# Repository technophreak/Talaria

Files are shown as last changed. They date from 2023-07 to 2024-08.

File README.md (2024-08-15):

# Mods for Talaria Sting R MX4 #

I will be documenting my mods so that others can benefit if they choose.

If you find a critical issue or improvement I will gladly apply changes and review pull requests.

Enjoy and be safe !
## References ##
* <a href="https://github.com/technophreak/Talaria/tree/main/Sting%20R%20MX4%20Pinout.md">Sting R MX4 Pinout</a> of some of the connectors

## Mods List ##
<table>
<tr>
  <th>Date</th>
  <th>Name</th>
  <th>Description</th>  
  <th>Difficulty</th>  
</tr>
<tr valign="top">
  <td nowrap>2023-07-28</td>
  <td nowrap><a href="https://github.com/technophreak/Talaria/tree/main/Mods/Street%20Legal">Street Legal</a></td>
  <td>Making the bike Street Legal by adding front and rear turn signals. Requires soldering and 3D printing</td>
  <td nowrap>Medium</td>  
</tr>
<tr valign="top">
  <td nowrap>2024-08-15</td>
  <td nowrap><a href="https://github.com/technophreak/Talaria/tree/main/Mods/AndroidAuto-Carplay">Android Auto/Carplay</a></td>
  <td>Adding a wireless/bluetooth 9.3" screen with Android Auto/Carplay. Requires soldering and 3D printing</td>
  <td nowrap>Low</td>  
</tr>

</table>

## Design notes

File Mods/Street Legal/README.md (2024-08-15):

# Making Talaria Sting R MX4 Street Legal #
<table>
  <tr>
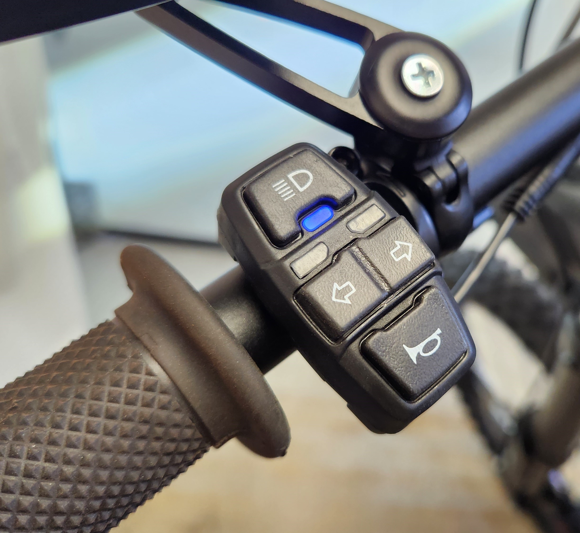
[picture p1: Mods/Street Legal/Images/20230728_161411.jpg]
    <td width="50%"></td>
    <td rowspan="2" width="50%"></td>
  </tr>
  <tr>
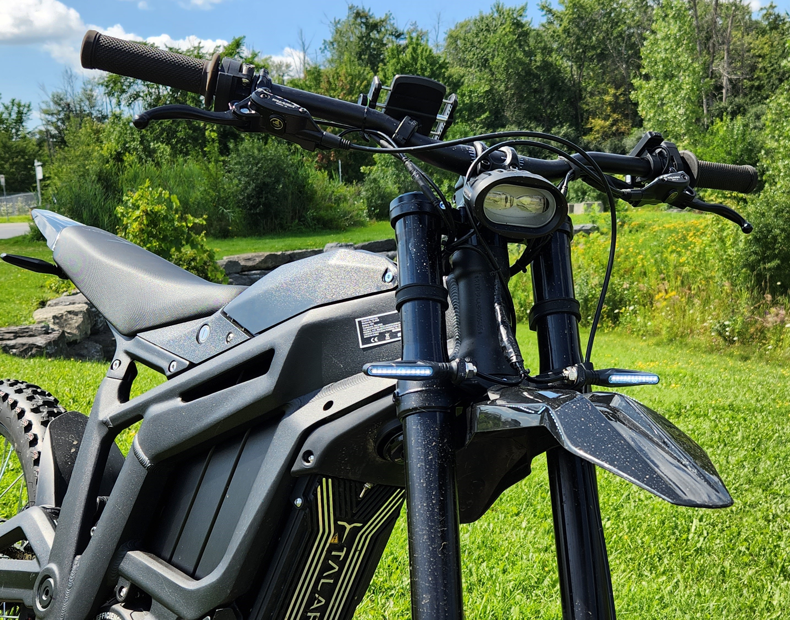
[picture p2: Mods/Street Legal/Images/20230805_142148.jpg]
    <td width="50%"></td>
  </tr>
</table>

This mod is what I found was the best way to make the MX4 street legal with as little as possible changes to the factory components.

The following (reversible) alterations to the factory components are required:
* Sacrifice (reversible) the horn button to reuse the 9 Pins connector on handlebar for 4 buttons controls.
* Move headlight connector pin to different location
* Add pin to backlight connector for brake light

## Bill of Material (sponsored links) ##
This is roughly a 80$ CAD (60$ USD) project
* Motorcycle Control Switch (4 buttons)
  * <a target="_blank" href="https://www.amazon.ca/dp/B093DDYNSB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">Amazon Canada</a>
  * <a target="_blank" href="https://www.amazon.com/gp/product/B09TBGLY7N/ref=ppx_yo_dt_b_asin_title_o02_s01?ie=UTF8&psc=1">Amazon USA</a>
* Motorcycle Indicators Turn Signals
  * <a target="_blank" href="https://www.amazon.ca/dp/B07SZDDZFJ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">Amazon Canada</a>
  * <a target="_blank" href="https://www.amazon.com/gp/product/B07T2YR63L/ref=ppx_yo_dt_b_asin_title_o02_s01?ie=UTF8&psc=1">Amazon USA</a>
* Bullet Crimp Terminals
  * <a target="_blank" href="https://www.amazon.ca/120pcs-Connector-Terminal-Insulation-Motorcycle/dp/B07DJ1SFSZ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">Amazon Canada</a>
  * <a target="_blank" href="https://www.amazon.com/gp/product/B07WCSHF6J/ref=ppx_yo_dt_b_asin_title_o02_s00?ie=UTF8&psc=1">Amazon USA</a>
* Waterproof connector (for pins)
  * <a target="_blank" href="https://www.amazon.ca/dp/B06XGV44T1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">Amazon Canada</a>
  * <a target="_blank" href="https://www.amazon.com/gp/product/B07HHYQ1W9/ref=ewc_pr_img_1?smid=A1EEONYNGVV4GN&psc=1">Amazon USA</a>
* M6 Button Head Screws
  * <a target="_blank" href="https://www.amazon.ca/gp/product/B099PX13F8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">Amazon Canada</a>
  * <a target="_blank" href="https://www.amazon.com/gp/product/B07DYCR2GY/ref=ppx_yo_dt_b_asin_title_o03_s01?ie=UTF8&psc=1">Amazon USA</a>
* <a target="_blank" href="https://www.amazon.ca/gp/product/B0BB8ML814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">Blinker Fluid</a>

## Tools Required (sponsored links) ##
These are tools I have purchased myself and have been working with for a while. I recommend if you do not already have equivalent.
* <a target="_blank" href="https://www.amazon.ca/gp/product/B07JL54N4X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">Wire Cable Cutter</a>
* <a target="_blank" href="https://www.amazon.ca/gp/product/B07X48MKWR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">Cable Stripper Pliers</a>
* <a target="_blank" href="https://www.amazon.ca/gp/product/B001AXD0EY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">Electrical Tape</a>
* <a target="_blank" href="https://www.amazon.ca/gp/product/B0C1G8S3Z2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">Soldering Iron</a>
* <a target="_blank" href="https://www.amazon.ca/gp/product/B0943TPRXK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">Soldering Wire with Flux</a>
* 3D Printer (Or access to one)
* Toolkit included with the MX4

## Instructions ##
**!!! INSTRUCTIONS NOT YET COMPLETE - WORK IN PROGRESS !!!**

### STEP 1 - 3D Printing ###
Print the <a href="https://github.com/technophreak/Talaria/blob/main/Mods/Street%20Legal/STLs/MX4%20Front%20Lights%20Bracket.stl">front</a> and <a href="https://github.com/technophreak/Talaria/blob/main/Mods/Street%20Legal/STLs/MX4%20Back%20Lights%20Bracket.stl">rear</a> brackets,

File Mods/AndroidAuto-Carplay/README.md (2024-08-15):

# Android Auto/Carplay #
For those who would be interested of using Carplay/Android Auto with your Talaria Sting R MX4, this is a decent option. You will require some PD65W USB-C charger and a USB-C to USB-C cable to power the screen. There is a removable bracket in the 3D printed models directory that you can print and fit it on the screen listed below.

***Note***: You will need some sort of isolation tape to prevent short circuiting multiple PD65W USB-C chargers. You can use kapton tape, included in the list.

* Wireless Carplay/Android Auto 9.3" Screen
  * <a target="_blank" href="https://www.amazon.ca/gp/product/B0BZ7XRMRW/ref=ppx_yo_dt_b_search_asin_title?ie=UTF8&psc=1">Amazon Canada</a>
  * <a target="_blank" href="https://www.amazon.com/dp/B0B7H3JTDF?psc=1&ref=ppx_yo2ov_dt_b_product_details">Amazon USA</a>
* PD65W Fast Charging Module Type-C USB
  * <a target="_blank" href="https://www.aliexpress.us/item/3256806830457021.html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">AliExpress</a>
* Handlebar Mount Clamp
  * <a target="_blank" href="https://www.amazon.ca/gp/product/B09RFGHSTK/ref=ppx_yo_dt_b_search_asin_title?ie=UTF8&psc=1">Amazon Canada (Order 2)</a>
  * <a target="_blank" href="https://www.amazon.com/gp/product/B07CZWQYD7/ref=ppx_yo_dt_b_asin_title_o01_s00?ie=UTF8&psc=1">Amazon USA</a>
    * Note: there are no real affordable options on Amazon USA for those. You can use the following link for a 2-piece set of bottle holders and use the clamps from those.
* Kapton tape
  * <a target="_blank" href="https://www.amazon.ca/Polyimide-Temperature-Resistant-Multi-Sized-Soldering/dp/B072Z92QZ2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">Amazon Canada</a>
  * <a target="_blank" href="https://www.amazon.com/dp/B072Z92QZ2?psc=1&ref=ppx_yo2ov_dt_b_product_details">Amazon USA</a>

You will need to print the following bracket to mount the screen on the handlebar: <a target="blank" href="https://github.com/technophreak/Talaria/blob/main/Mods/Street%20Legal/STLs/LCDMount.stl">LCD Mount Bracket</a>

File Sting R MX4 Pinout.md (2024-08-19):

# Pinouts for Talaria Sting R MX4 #
<table>
	<thead>
    <tr>
      <th colspan="4">Handlebars - 9 Pins Connector (Horn)</td>
    </tr>
	</thead>
  <tr>
    <th><b>Color</b></th>
    <th><b>Wire Harness</b></th>
    <th><b>Description</b></th>
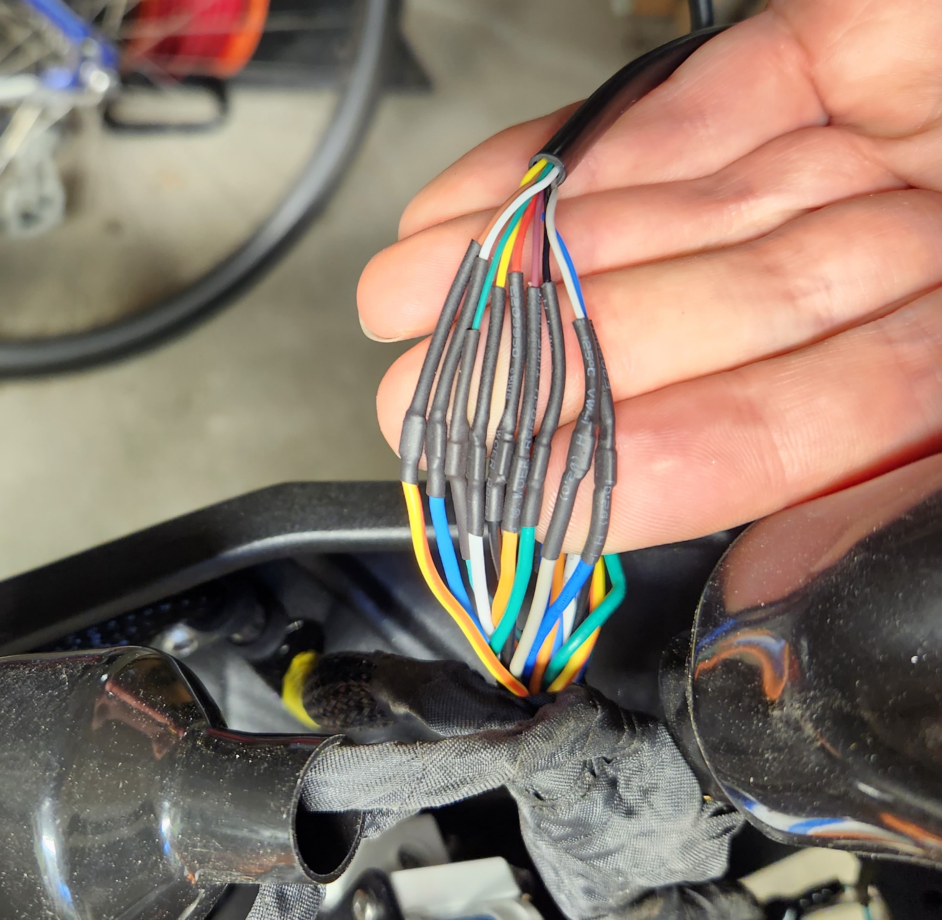
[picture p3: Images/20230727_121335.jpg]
    <td rowspan="11" align="center" width="25%"></td>
  </tr>  
  <tr>
    <td>Black</td>
    <td>Green</td>
    <td>Negative 12V</td>    
  </tr>
  <tr>
    <td>Red</td>
    <td>Black</td>
    <td>Positive 12V</td>    
  </tr>
    <tr>
    <td>Green</td>
    <td>Teal</td>
    <td>Horn Positive Terminal</td>    
  </tr>
  <tr>
    <td>Yellow</td>
    <td>White</td>
    <td>Headlight Connector</td>    
  </tr>  
  <tr>
    <td>White</td>
    <td>Light Blue</td>
    <td>Front / Rear Turn Signals (Left ?)</td>    
  </tr>  
  <tr>
    <td>Purple</td>
    <td>Orange</td>
    <td>Front / Rear Turn Signals (Right ?)</td>    
  </tr>   
  <tr>
    <td>Blue</td>
    <td>Blue</td>
    <td>Headlight Connector</td>    
  </tr>
  <tr>
    <td>Grey</td>
    <td>Grey</td>
    <td>Unknown</td>    
  </tr>
    <tr>
    <td>Brown</td>
    <td>Yellow/Orange</td>
    <td>Unknown</td>    
  </tr>
</table>

<table>
	<thead>
    <tr>
      <th colspan="4">Handlebars - 9 Pins Connector (Display)</td>
    </tr>
	</thead>
  <tr>
    <th><b>Color</b></th>
    <th><b>Wire Harness</b></th>
    <th><b>Description</b></th>
    <td rowspan="11" align="center" width="25%"><!--<img src="https://github.com/technophreak/Talaria-Sting-R-MX4/blob/main/Images/20230727_121335.jpg">--></td>
  </tr>  
  <tr>
    <td>Black</td>
    <td>TBD</td>
    <td>Negative 12V</td>    
  </tr>
  <tr>
    <td>Red</td>
    <td>TBD</td>
    <td>Positive 12V</td>    
  </tr>
    <tr>
    <td>Green</td>
    <td>TBD</td>
    <td>CAN Low</td>    
  </tr>
  <tr>
    <td>Yellow</td>
    <td>TBD</td>
    <td>CAN High</td>    
  </tr>  
  <tr>
    <td>White</td>
    <td>TBD</td>
    <td>Unknown</td>    
  </tr>  
  <tr>
    <td>Purple</td>
    <td>TBD</td>
    <td>Unknown</td>    
  </tr>   
  <tr>
    <td>Blue</td>
    <td>TBD</td>
    <td>Unknown</td>    
  </tr>
  <tr>
    <td>Grey</td>
    <td>TBD</td>
    <td>Unknown</td>    
  </tr>
    <tr>
    <td>Brown</td>
    <td>TBD</td>
    <td>Unknown</td>    
  </tr>
</table>

<table>	
    <thead>
  	  <tr>
  	    <th colspan="3">Front - 4 Pins Headlight Connector</td>
      </tr>
    </thead>
  <tr>
    <th><b>Color</b></th>
    <th><b>Description</b></th>
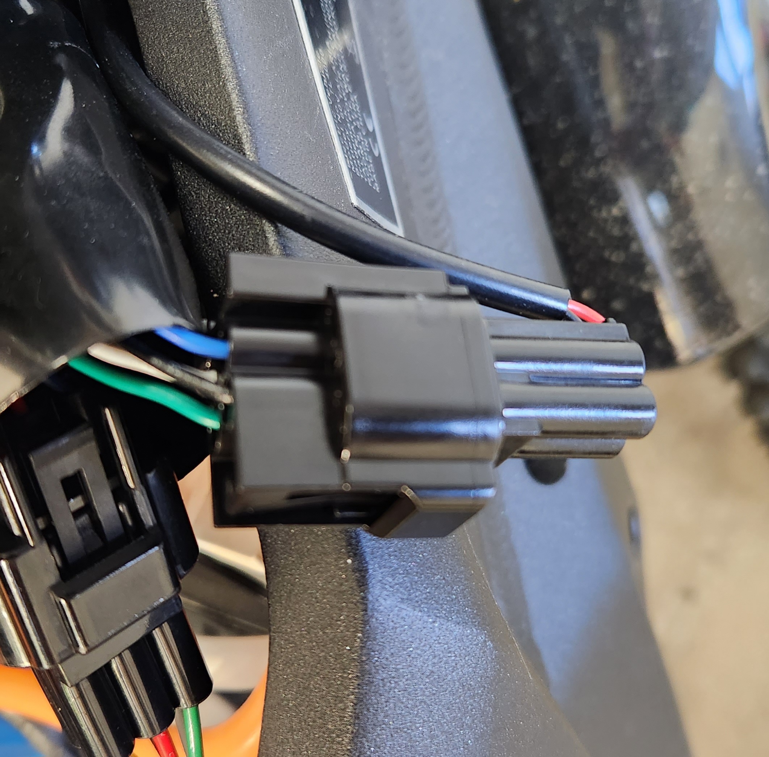
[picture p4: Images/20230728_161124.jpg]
    <td rowspan="5" align="center" width="25%"></td>
  </tr>  
  <tr>
    <td>Green</td>
    <td>Negative 12V</td>    
  </tr>
  <tr>
    <td>Black</td>
    <td>Positive 12V</td>    
  </tr>
  <tr>
    <td>White</td>
    <td>9 Pins Handlebars Connector - Yellow (low beam ?)</td>    
  </tr>	 
  <tr>
    <td>Blue</td>
    <td>9 Pins Handlebars Connector - Blue (high beam ?)</td>    
  </tr>	 
</table>

<table>
  	<thead>
      <tr>
          <th colspan="3">Front - 3 Pins Turn Signal Connector</td>
      </tr>
    </thead>
  <tr>
    <th><b>Color</b></th>
    <th><b>Description</b></th>
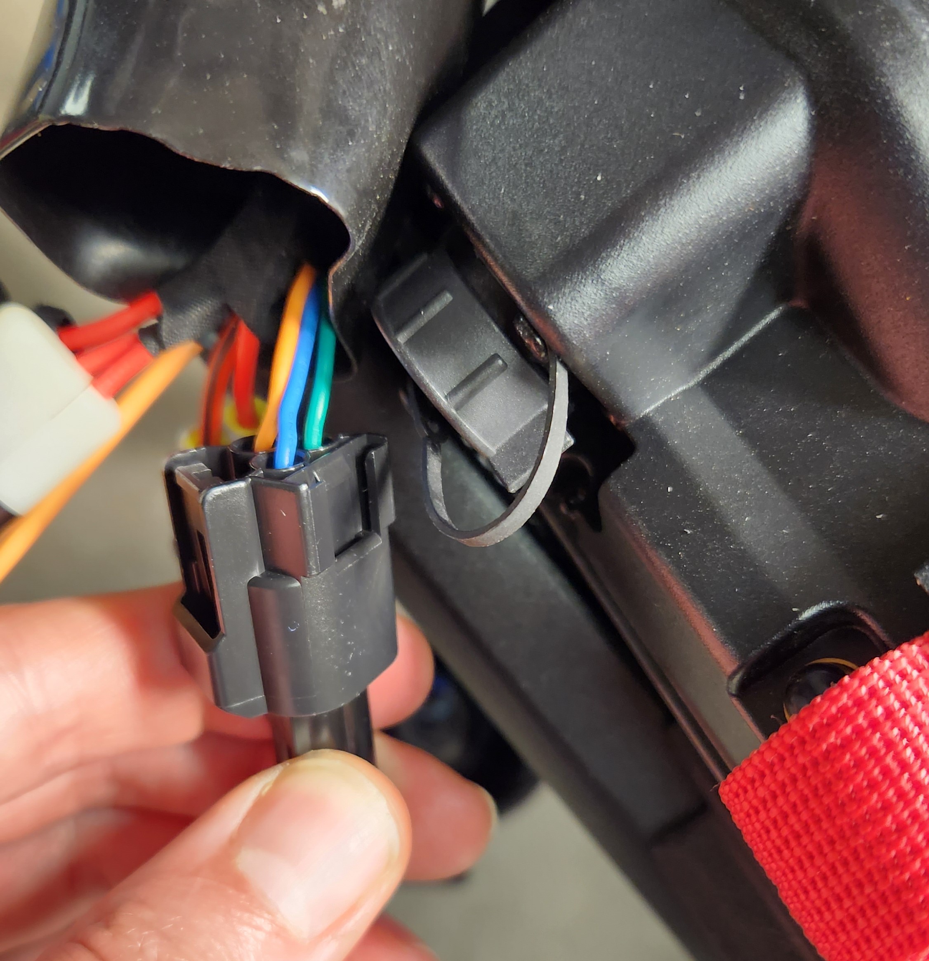
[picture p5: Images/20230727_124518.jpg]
    <td rowspan="5" align="center" width="25%"></td>    
  </tr>  
  <tr>
    <td>Green</td>
    <td>Negative 12V</td>    
  </tr>
  <tr>
    <td>Light Blue</td>
    <td>9 Pins Handlebars Connector - White (Left ?)</td>    
  </tr>	 
  <tr>
    <td>Orange</td>
    <td>9 Pins Handlebars Connector - Purple (Right ?)</td>    
  </tr>	 
</table>		

<table>
  	<thead>
      <tr>
          <th colspan="3">Back - Turn Signal Individual Bullet Plugs</td>
      </tr>
    </thead>
  <tr>
    <th><b>Color</b></th>
    <th><b>Description</b></th>
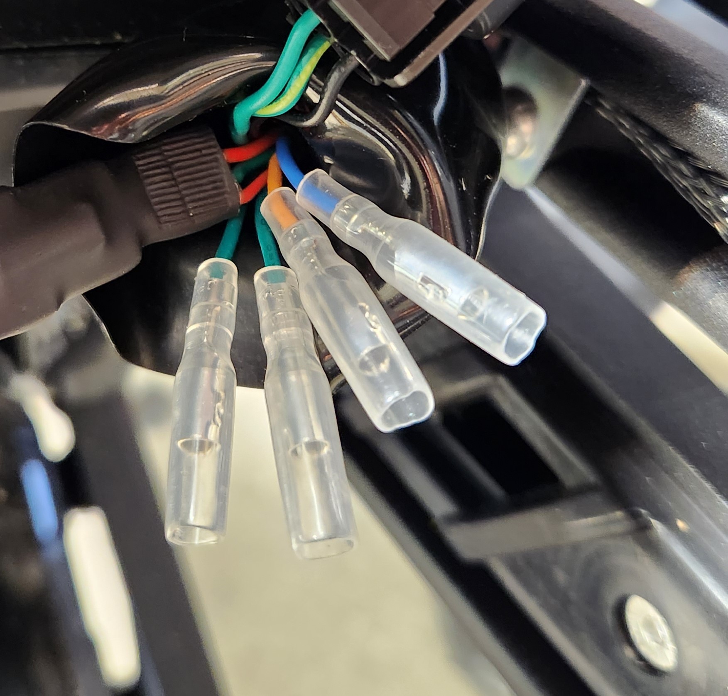
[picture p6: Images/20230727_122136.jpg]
    <td rowspan="5" align="center" width="25%"></td>        
  </tr>  
  <tr>
    <td>Green</td>
    <td>Negative 12V</td>    
  </tr>
  <tr>
    <td>Light Blue</td>
    <td>9 Pins Handlebars Connector - White (Left ?)</td>    
  </tr>	 
  <tr>
    <td>Orange</td>
    <td>9 Pins Handlebars Connector - Purple (Right ?)</td>    
  </tr>	 
  <tr>
    <td>Green</td>
    <td>Negative 12V</td>    
  </tr>  
</table>

<table>
  	<thead>
      <tr>
          <th colspan="3">Rear - 3 Pins Tail Light Connector</td>
      </tr>
    </thead>
  <tr>
    <th><b>Color</b></th>
    <th><b>Description</b></th>
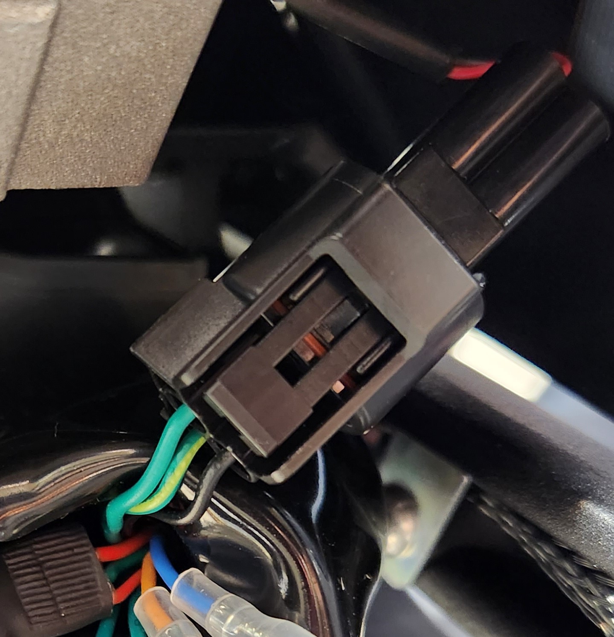
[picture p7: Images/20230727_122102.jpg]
    <td rowspan="4" align="center" width="25%"></td>            
  </tr>  
  <tr>
    <td>Green</td>
    <td>Negative 12V</td>    
  </tr>
  <tr>
    <td>Black</td>
    <td>Positive 12V</td>    
  </tr>	 
  <tr>
    <td>Green & Yellow</td>
    <td>+12 (Activated by Brakes)</td>    
  </tr>	 
</table>

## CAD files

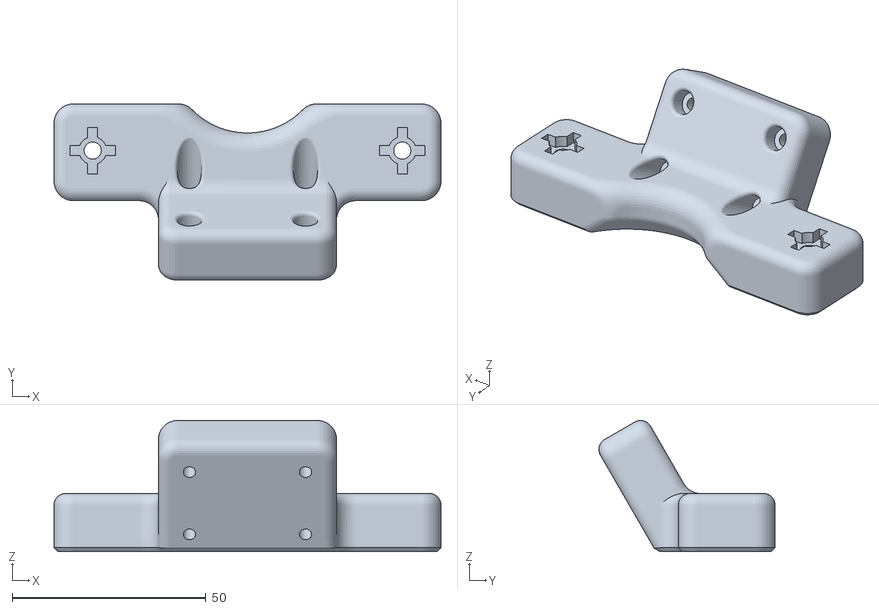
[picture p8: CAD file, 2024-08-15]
Mods/AndroidAuto-Carplay/STLs/LCDMount.stl
100.0 x 45.5 x 33.9

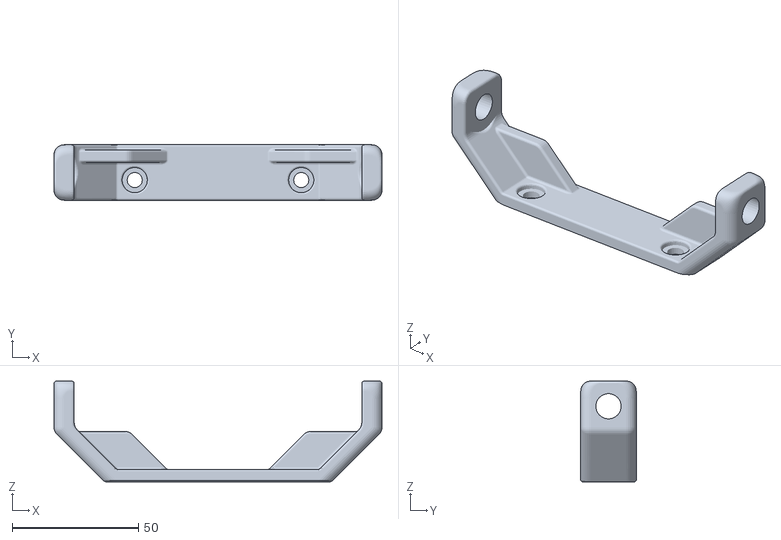
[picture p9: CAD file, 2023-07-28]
Mods/Street Legal/STLs/MX4 Back Lights Bracket.stl
130.0 x 22.0 x 40.0

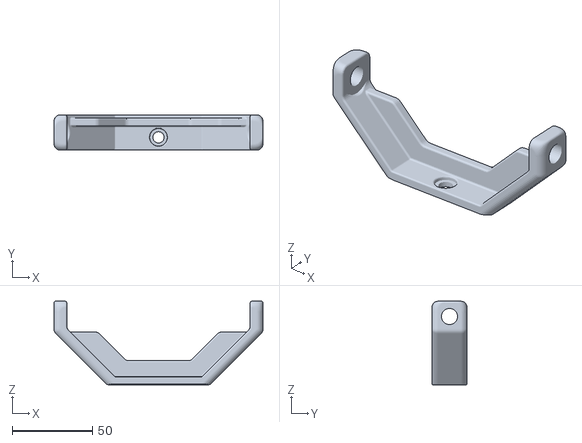
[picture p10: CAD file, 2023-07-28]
Mods/Street Legal/STLs/MX4 Front Lights Bracket.stl
130.0 x 22.0 x 52.0

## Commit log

2023-07-28 Add link for M6 Screws
2023-07-28 Change part Orientation
    [MX4 Back Lights Bracket.stl, MX4 Front Lights Bracket.stl]
2023-07-28 Add image for headlight connector
2023-08-07 Reorganize folder structure
    [MX4 Back Lights Bracket.stl, MX4 Front Lights Bracket.stl]
2023-08-07 Add pinout of display connector
2024-08-15 Added mount for LCD
    [LCDMount.stl]
2024-08-15 Moved mod to different directory
    [LCDMount.stl]
